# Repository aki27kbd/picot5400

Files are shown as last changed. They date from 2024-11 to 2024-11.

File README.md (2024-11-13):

# picot5400

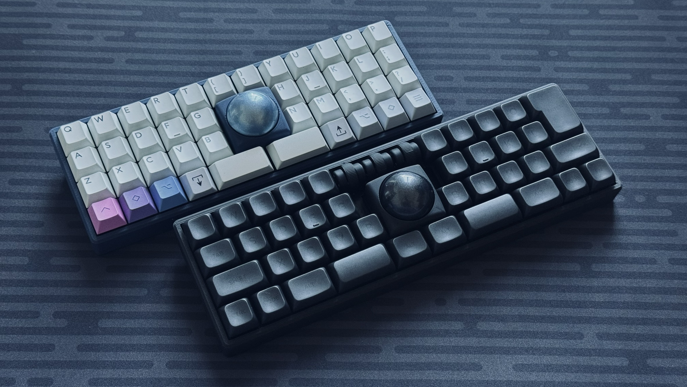
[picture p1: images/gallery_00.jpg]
picot5400_readme_00


## Introduction
picot5400 is a micro controller (RP2040) and trackball sensor (PMW3360) module for mechanical keyboard. Module size is 2u x 2u (38mm x 38mm) so that it can be easily implemented with mechanical keyboard design. The picot5400 allows designers to quickly and easily implement a trackball keyboard with only key matrix circuit and PCB.

## Features
- On-board MCU (RP2040) allows a full functional firmware with a trackball, vial and RGB matrix
- High-performance sensor (PMW3360) up to 12,000 cpi
- USB connection flexibility - an on-board Type-C connector as well as a JST connector for Unified Daughterboards
- Sufficient GPIO pins available - 21 pins via 24-pin flexible flat cable and 7 pins via through holes.
- Bearing roller support with a smooth ball handling and easy assembly

## How to Use
Please visit the docs for [consumers](doc/buildguide.md) and [designers](doc/designguide.md).

## Previews

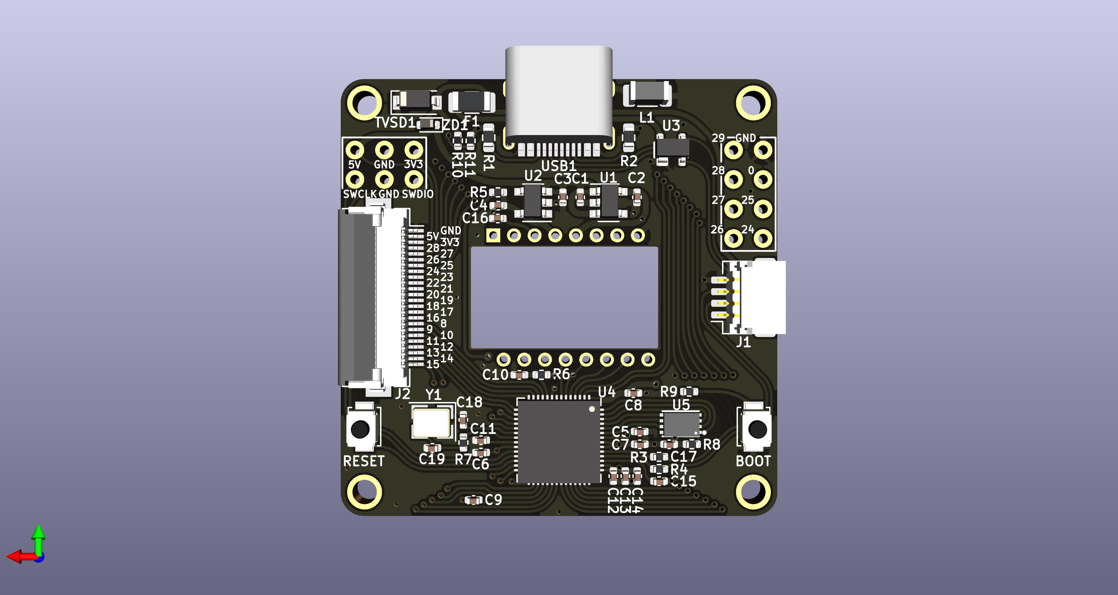
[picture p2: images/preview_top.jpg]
picot5400_preview_top


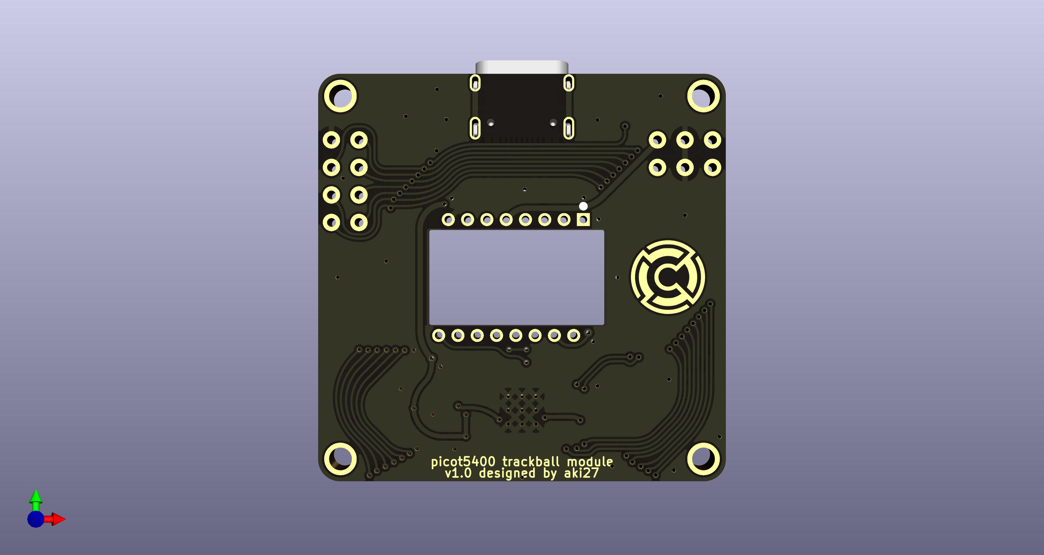
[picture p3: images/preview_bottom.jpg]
picot5400_preview_bottom


## Reference Keyboards

[picot_O44](https://github.com/aki27kbd/picot_o44)  
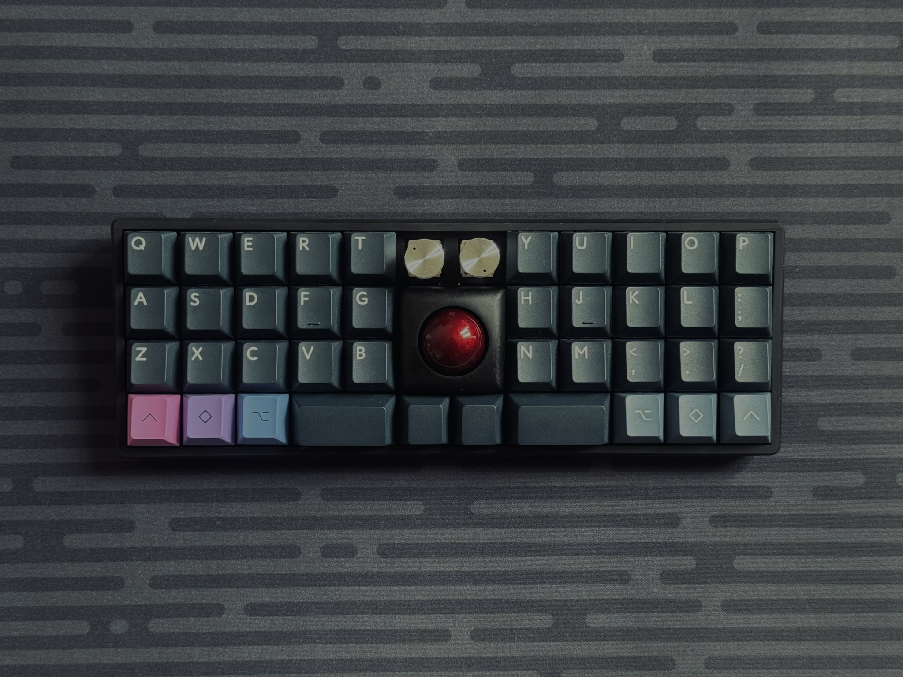
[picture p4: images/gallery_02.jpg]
picot_O44


[picot_R40](https://github.com/aki27kbd/picot_r40)
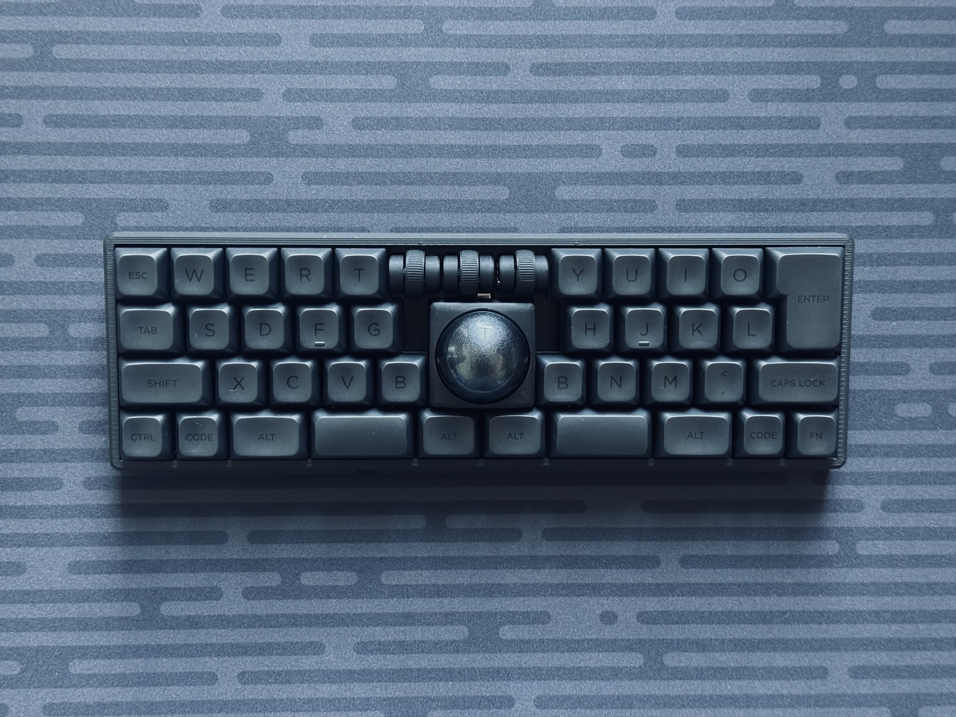
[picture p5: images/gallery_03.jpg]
picot_R40


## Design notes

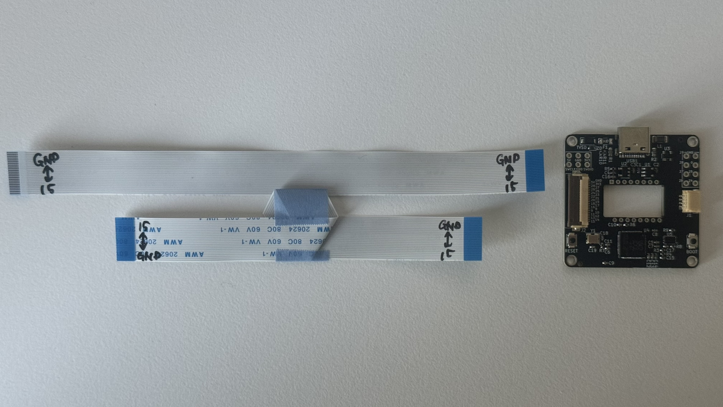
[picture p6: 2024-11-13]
images/design/FFC_02.jpg

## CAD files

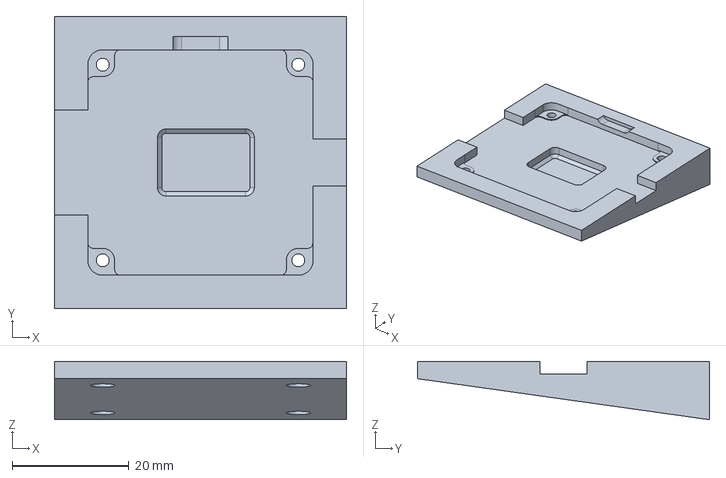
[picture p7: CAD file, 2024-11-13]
resources/picot5400_case_sample_8deg.step
50.0 x 50.0 x 10.0 mm

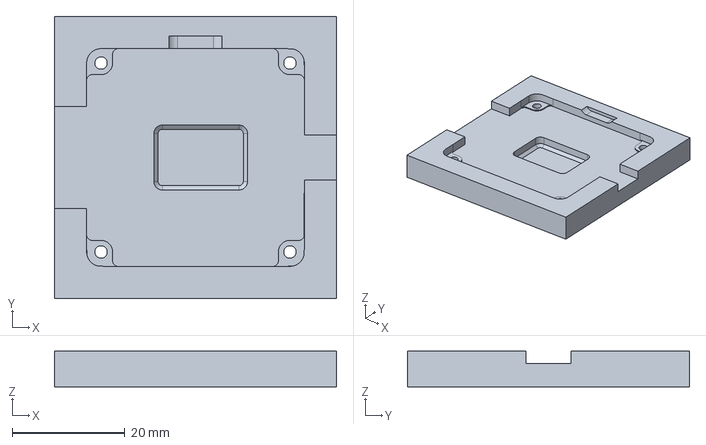
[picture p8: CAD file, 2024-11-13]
resources/picot5400_case_sample.step
50.0 x 50.0 x 6.30 mm

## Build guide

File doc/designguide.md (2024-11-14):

# Design Guide

picot5400を用いたキーボードのデザインガイドになります。picot5400を用いることで、トラックボール付キーボードの設計がしやすくなります。  
picot5400を採用したキーボードであるpicot_O44を例に挙げます。下図はpicot_O44の全体構成概略図になります。  
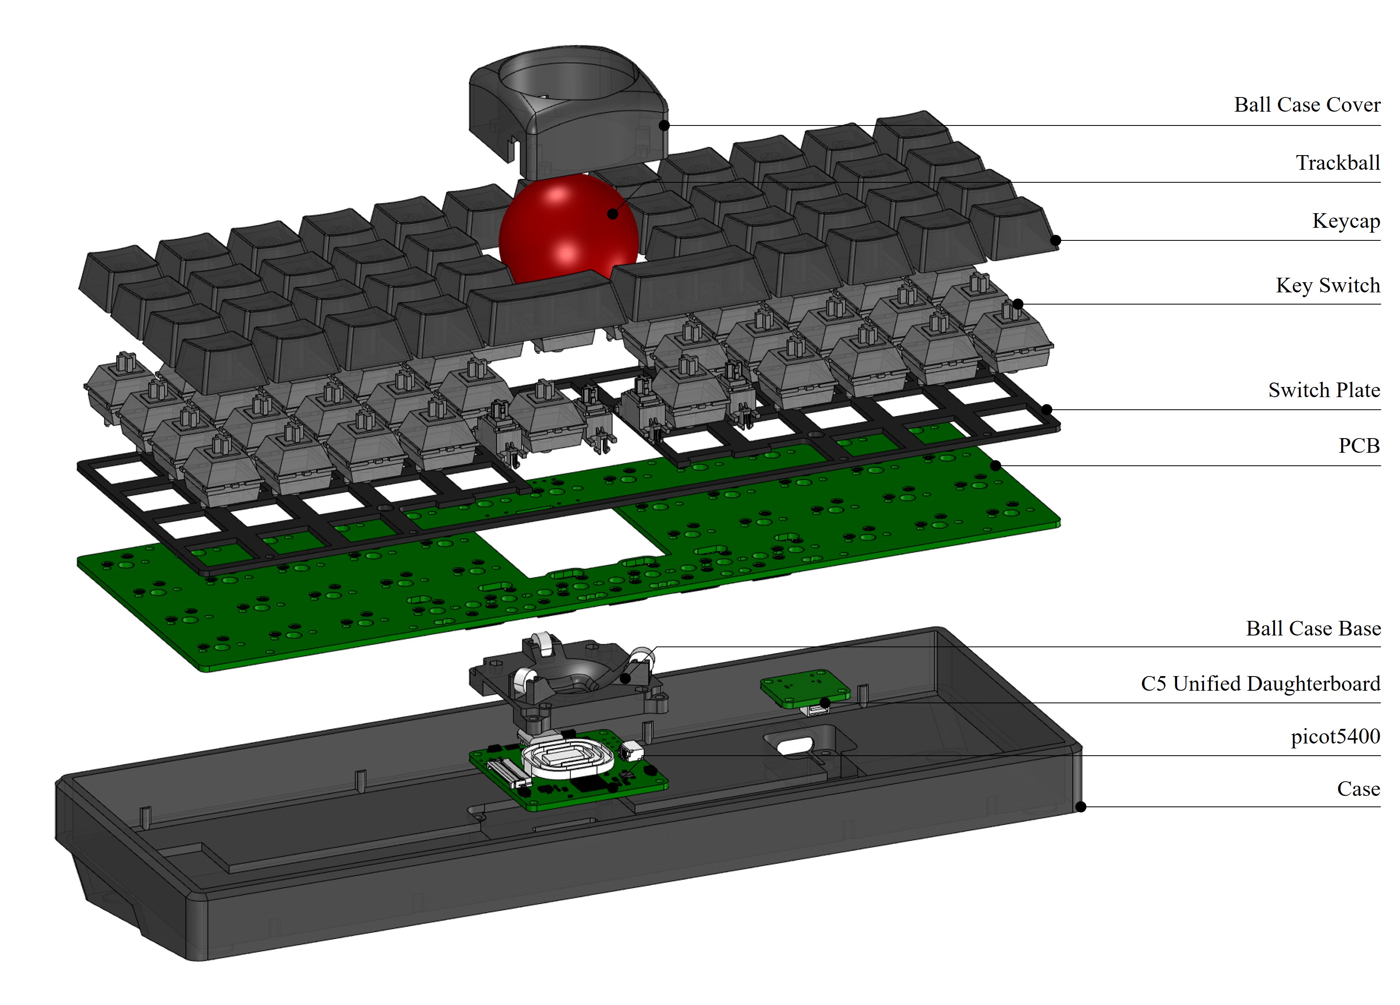
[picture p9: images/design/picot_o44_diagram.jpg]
picot_o44_diagram
  

picot_O44では、picot5400をケースに固定し、同じくケースに固定したUnified DaughterboardとJSTケーブルで接続します。  
キーマトリクス基板（PCB）はpicot5400とフレキシブルフラットケーブルで接続されます。  
このデザインガイドでは、キーマトリクス基板とケースの設計について留意すべき点を中心にまとめています。一般的なキーボード用PCBやケースデザインの基礎については他資料を参照してください。

## PCB Design

キーボードを設計する際は、picot5400とフレキシブルフラットケーブルを介して接続するキーマトリクス基板が必要になります。マイコン（RP2040）およびセンサー（PMW3360）は全てpicot5400側に搭載されているので、キーマトリクス基板はGPIOと電源線のみで構成することが可能です。

### Circuit Design
回路図には、左側のFFCコネクタと右側のキーマトリクスが必要です。  
[picot_o44_schematics.pdf](https://github.com/aki27kbd/picot_o44/blob/main/doc/picot_o44_schematics.pdf)  
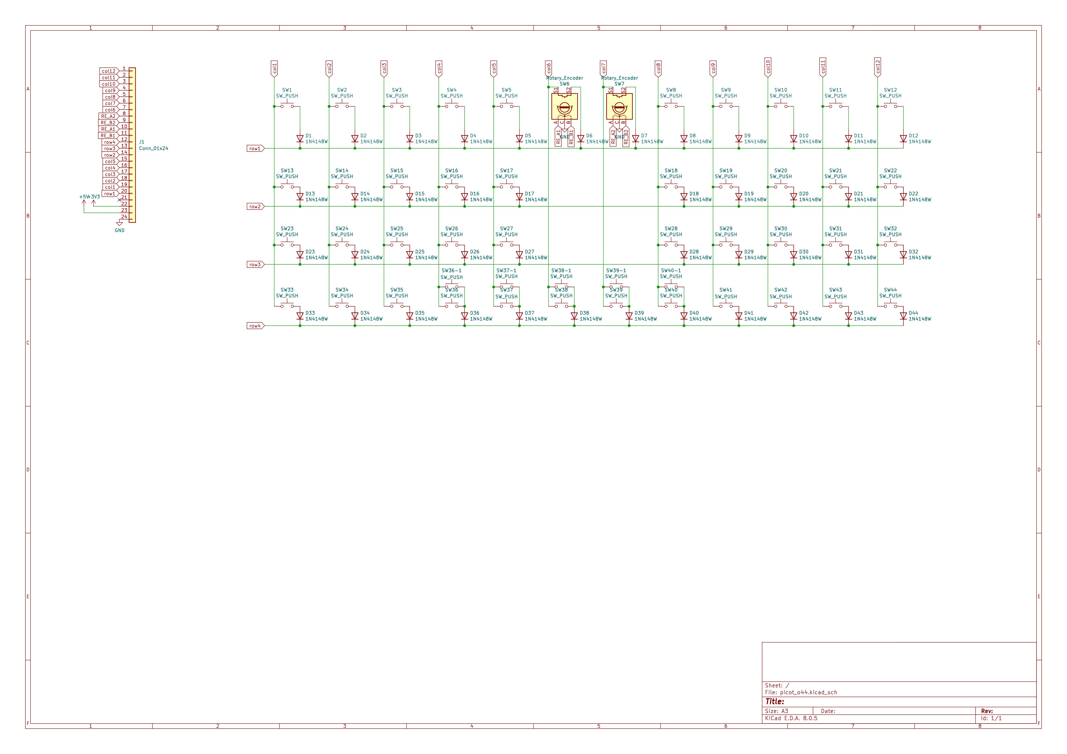
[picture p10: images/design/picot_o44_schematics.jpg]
picot_o44_schematics


FFCコネクタは、使用するケーブルの種類（ストレート・反転）に応じて、ピンの配置を反転させてください。picot_O44では、ストレートタイプのケーブルを用いて、基板底面にコネクタを配置しています。下図のように、***ストレートタイプのケーブルを用いる場合はpicot5400とキーマトリクス基板でコネクタのピンアサインが反転することに注意してください。***  
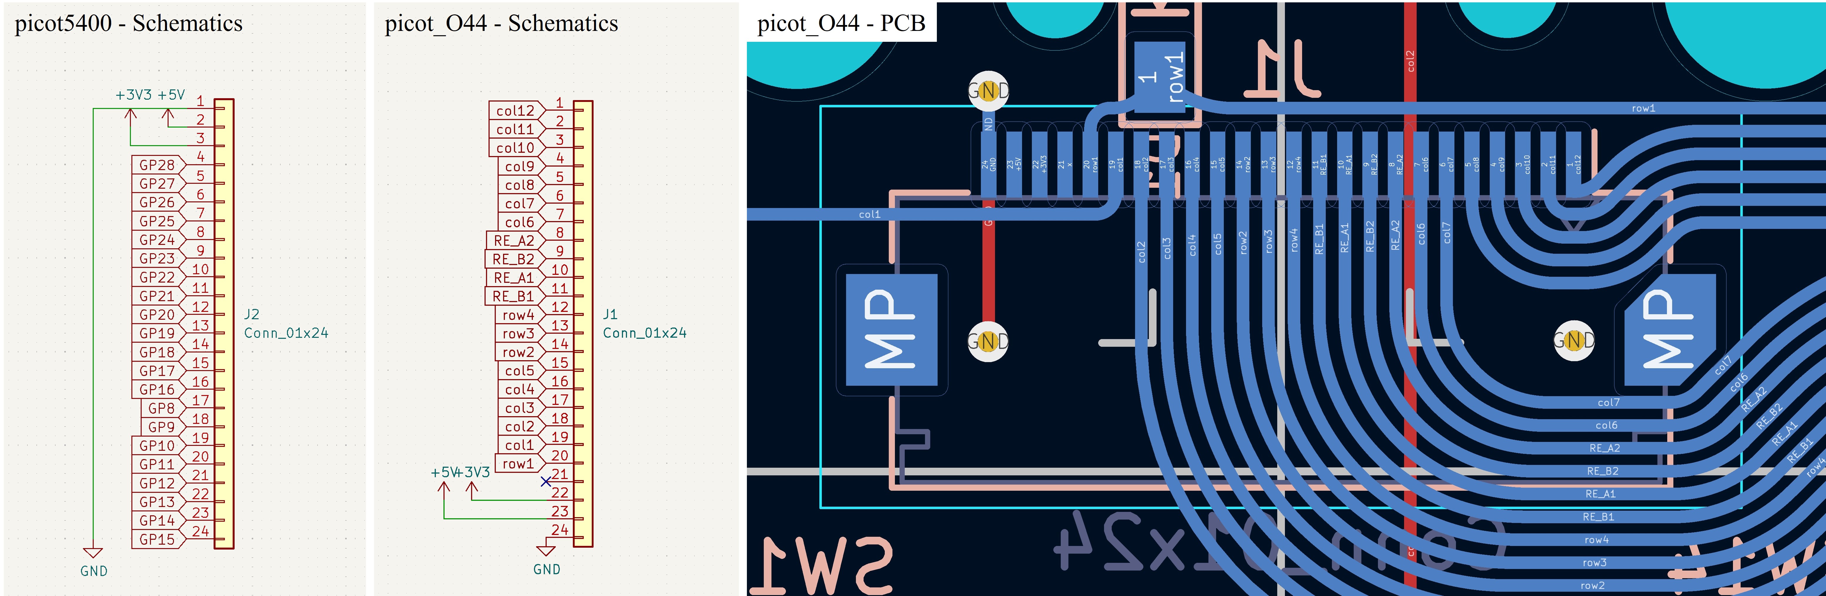
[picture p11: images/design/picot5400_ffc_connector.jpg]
picot5400_ffc_connector


コネクタのピンアサインを誤って逆にしてしまった場合でも、ケーブルを折り曲げることで対応可能です。  
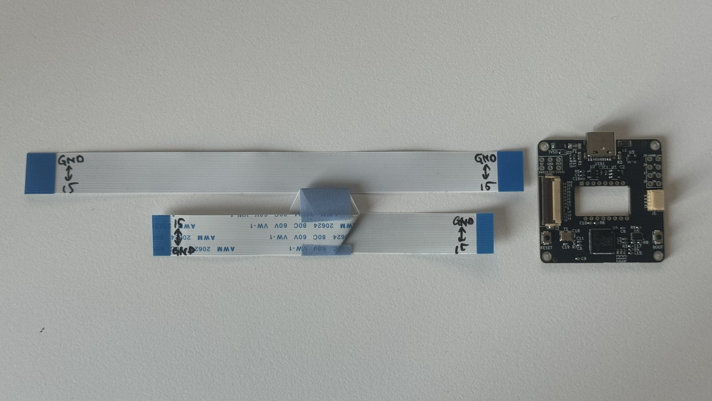
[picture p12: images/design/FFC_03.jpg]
FFC_reversed


キーマトリクス側は、通常のキーボードと同様に設計してください。FFCケーブルで接続した場合、最大21本のGPIOを使用することが可能なので、キー数の多いキーボードやロータリーエンコーダにも十分に対応可能です。  
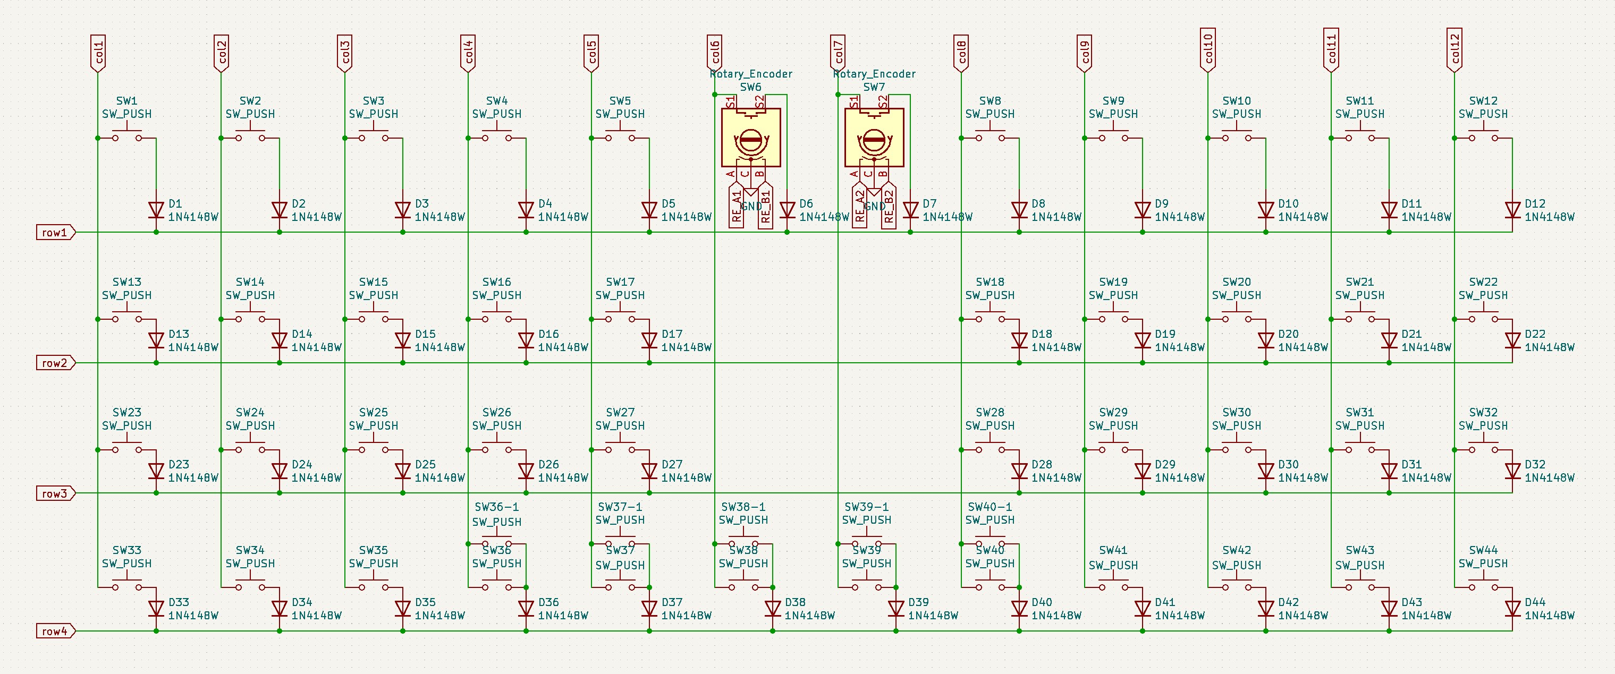
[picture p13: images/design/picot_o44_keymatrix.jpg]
Keymatrix


### PCB Design
キーマトリクス基板側のFFCコネクタは、KiCADのデフォルトライブラリに入っている「Hirose_FH12-24S-0.5SH_1x24-1MP_P0」を使用します。
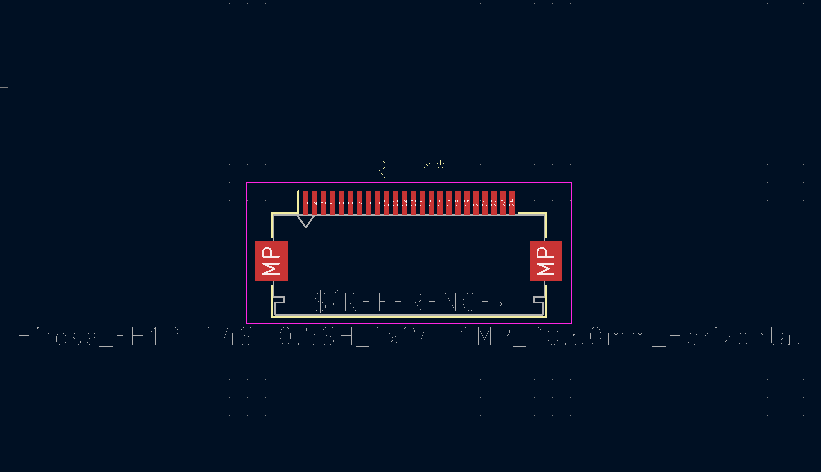
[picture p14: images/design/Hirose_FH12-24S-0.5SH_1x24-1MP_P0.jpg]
Hirose_FH12-24S-0.5SH_1x24-1MP_P0


コネクタはキーの間に設置することが可能です。スイッチソケットを扱う場合もキー間に設置可能です。  
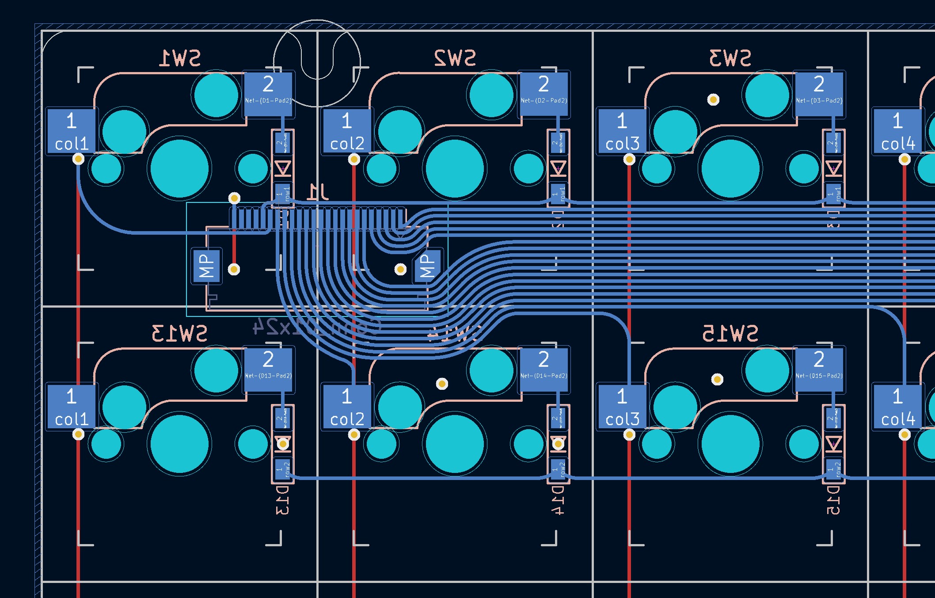
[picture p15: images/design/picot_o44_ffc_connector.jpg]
picot_o44_ffc_connector


picot_O44のようにキーボードの中央にトラックボールを設ける場合、キーマトリクス基板の該当箇所に必要な開口を設けてください。  
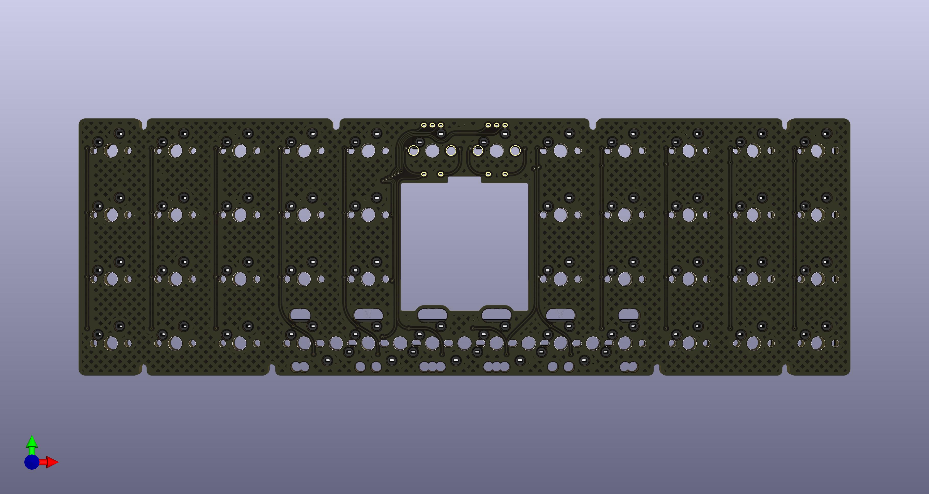
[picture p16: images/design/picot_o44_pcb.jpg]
PCB


picot_O44のPCBには、picot5400のUSB Type-Cとの干渉を避けるための切り欠きが設けられています。設計上はPCBとUSB Type-Cは干渉しませんが、PCBが想定以上に撓んだ場合を想定して該当箇所を切り欠いています。  
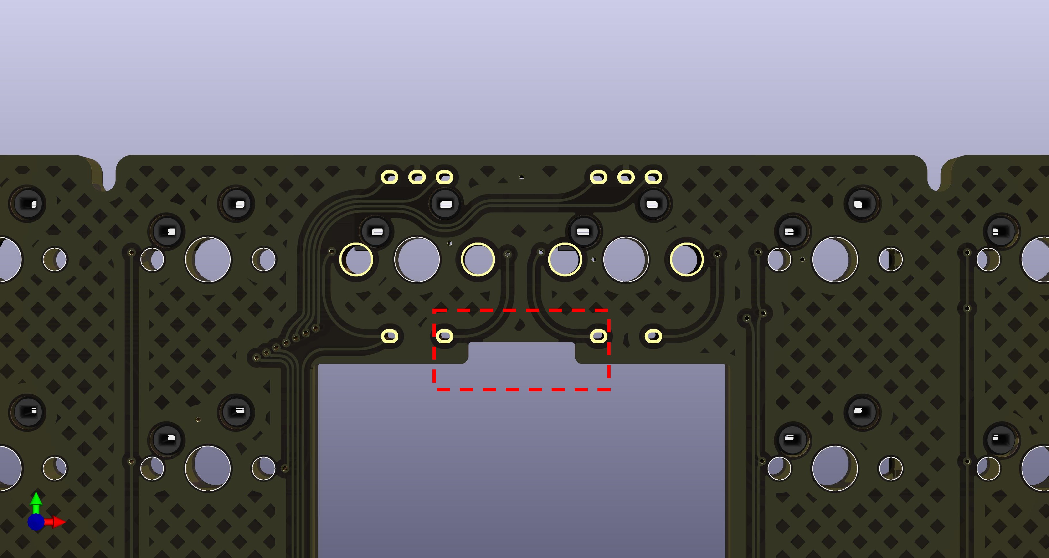
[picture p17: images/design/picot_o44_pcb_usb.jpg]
PCB_USB


また、picot_O44のようにスタビライザーを固定するためにPCBが開口側にはみ出す場合もあります。その場合はボールケース（ベース）の切り欠きがある側をスタビライザー側になるように設計してください。
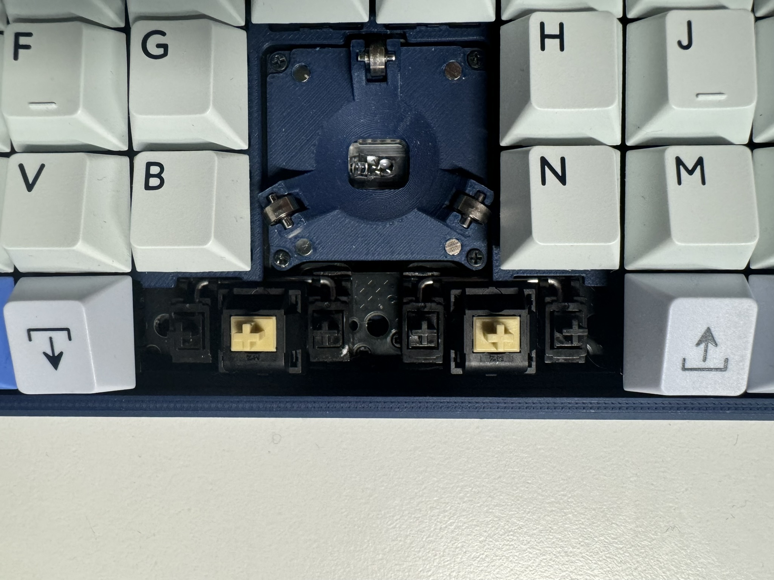
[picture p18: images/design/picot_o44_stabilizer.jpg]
PCB_stabilizer


## Case Design
picot5400は、キーボードのケースやボトムプレートなど、キーマトリクス基板から独立したものに固定することを推奨しています。これはキーの押下に伴う基板の揺れがセンサーとボールに伝わりにくくするためです。

picot_O44では、picot5400を直接キーボードのケースに固定し、キーマトリクス基板はケースを介して間接的に接触する設計としています。
断面図での各パーツの構成は下図の通りです。  
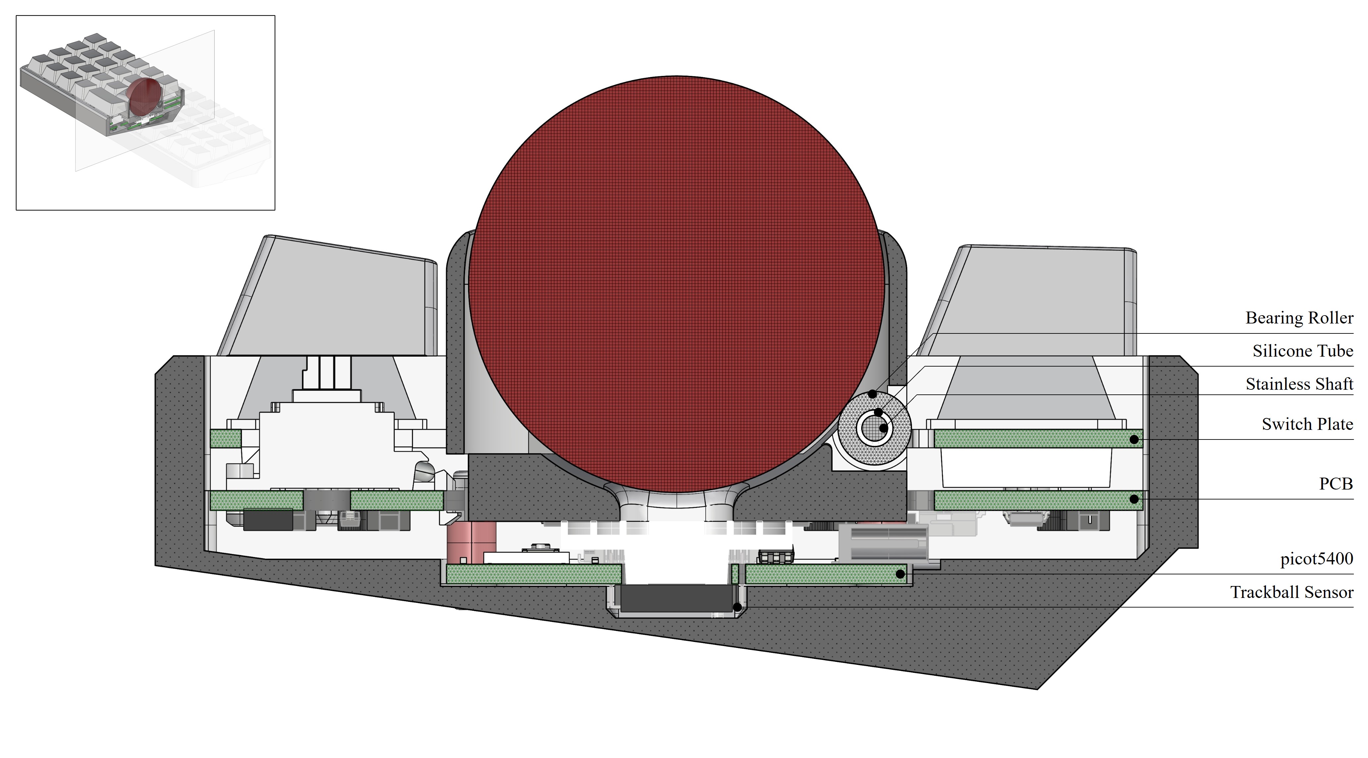
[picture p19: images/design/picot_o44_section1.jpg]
picot_o44_section1
  

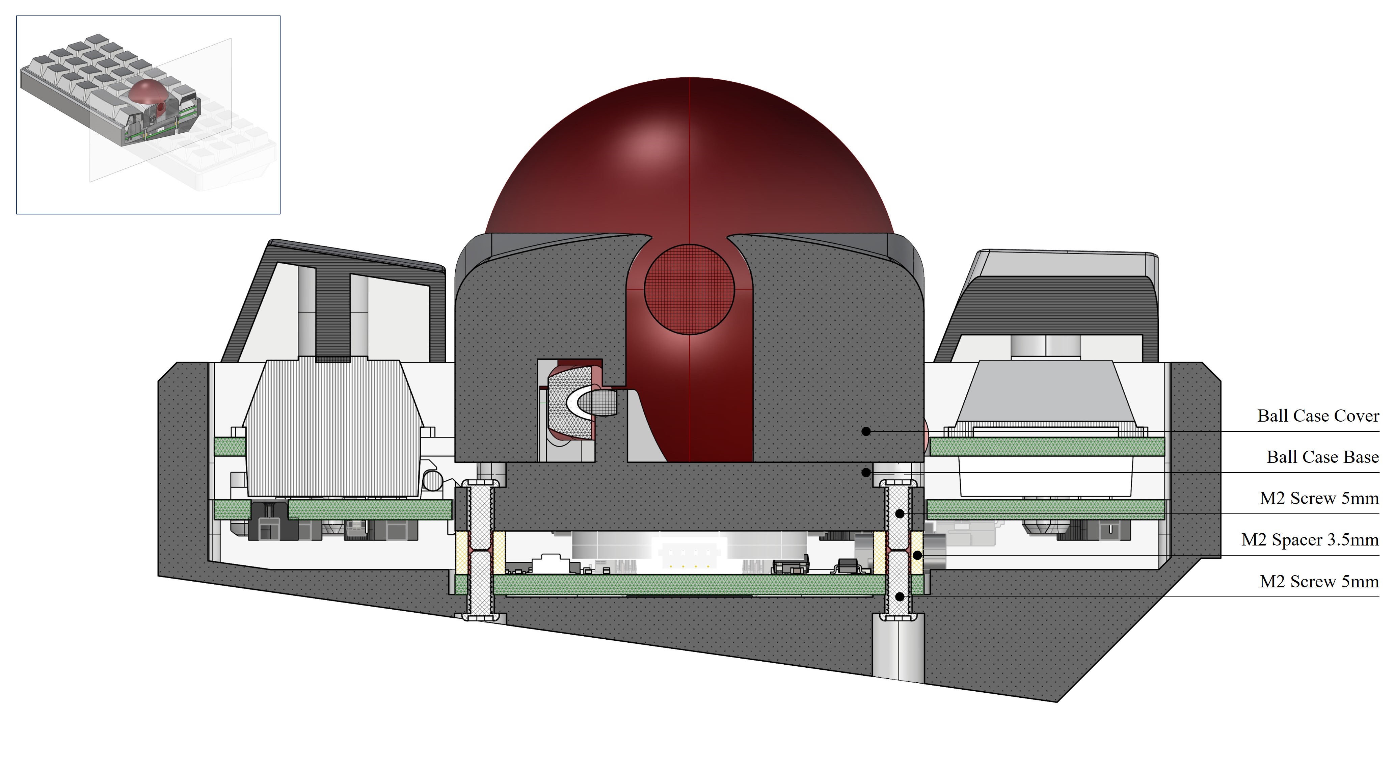
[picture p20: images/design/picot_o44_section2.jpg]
picot_o44_section2
  

キーボードのケースやボトムプレートに固定する際のねじ穴寸法は、下の寸法図を参考にしてください。  
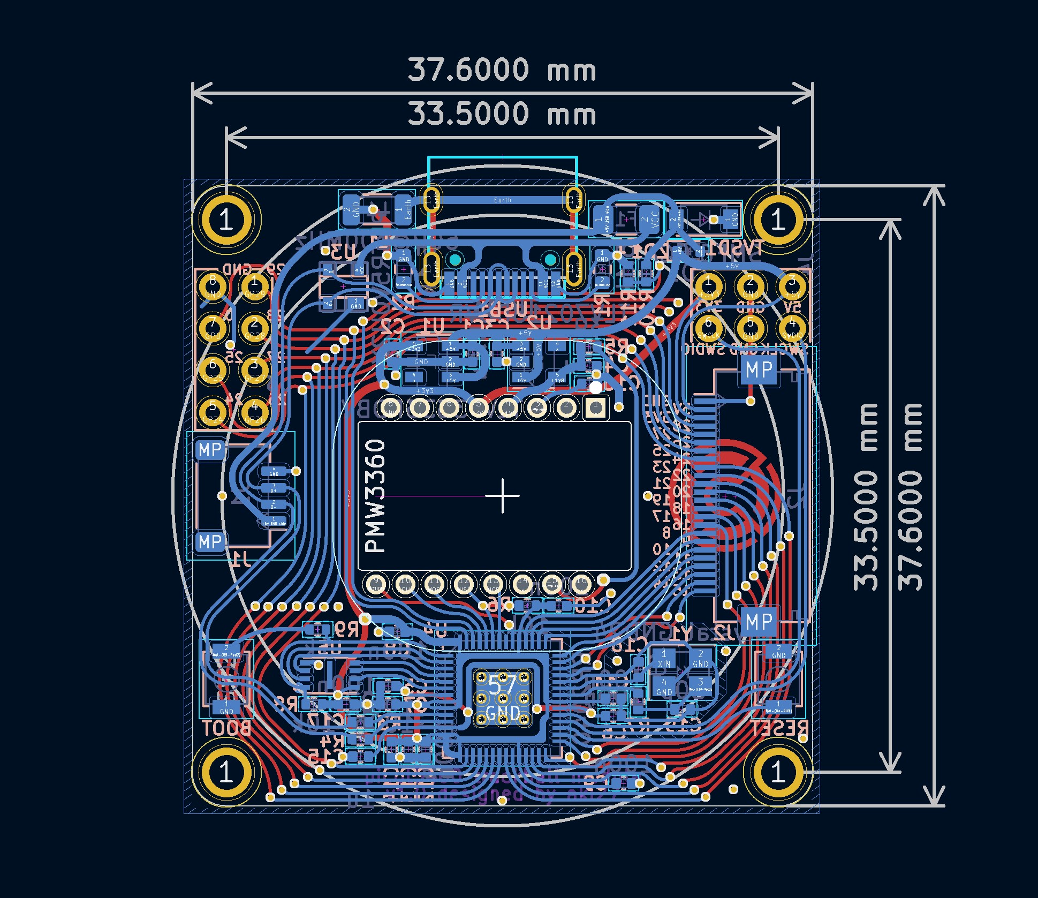
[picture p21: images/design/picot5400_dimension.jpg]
picot5400_dimension
  

また、3DプリンタやCNCで製造する立体的なケースを設計する際は、下記資料内の[picot5400_case_sample](/resources/picot5400_case_sample.step)を参照してください。  
下記ポイントに注意して設計を進めてください。
- picot5400の下部にセンサーが出っ張るため干渉を避ける必要があります
- USB Type-Cコネクタが基板外径線からはみ出しているので、基板をケースに埋め込む際はコネクタと干渉しないよう切り欠きを設ける必要があります
- FFCケーブル、JSTケーブルは基板上面のコネクタに接続するので、基板をケースに埋め込む際はケーブルルート用の切り欠きを設ける必要があります

USBコネクタは、picot5400に搭載されているものを用いない場合はJSTケーブルでUnified Daughterboardと接続することになります。  
Unified Daughterboardに関する設計は[公式ドキュメント](https://unified-daughterboard.github.io/#/?id=unified-daughterboard)を参照してください。

## Resources
[picot5400_schematics](/resources/picot5400_schematics.pdf)  
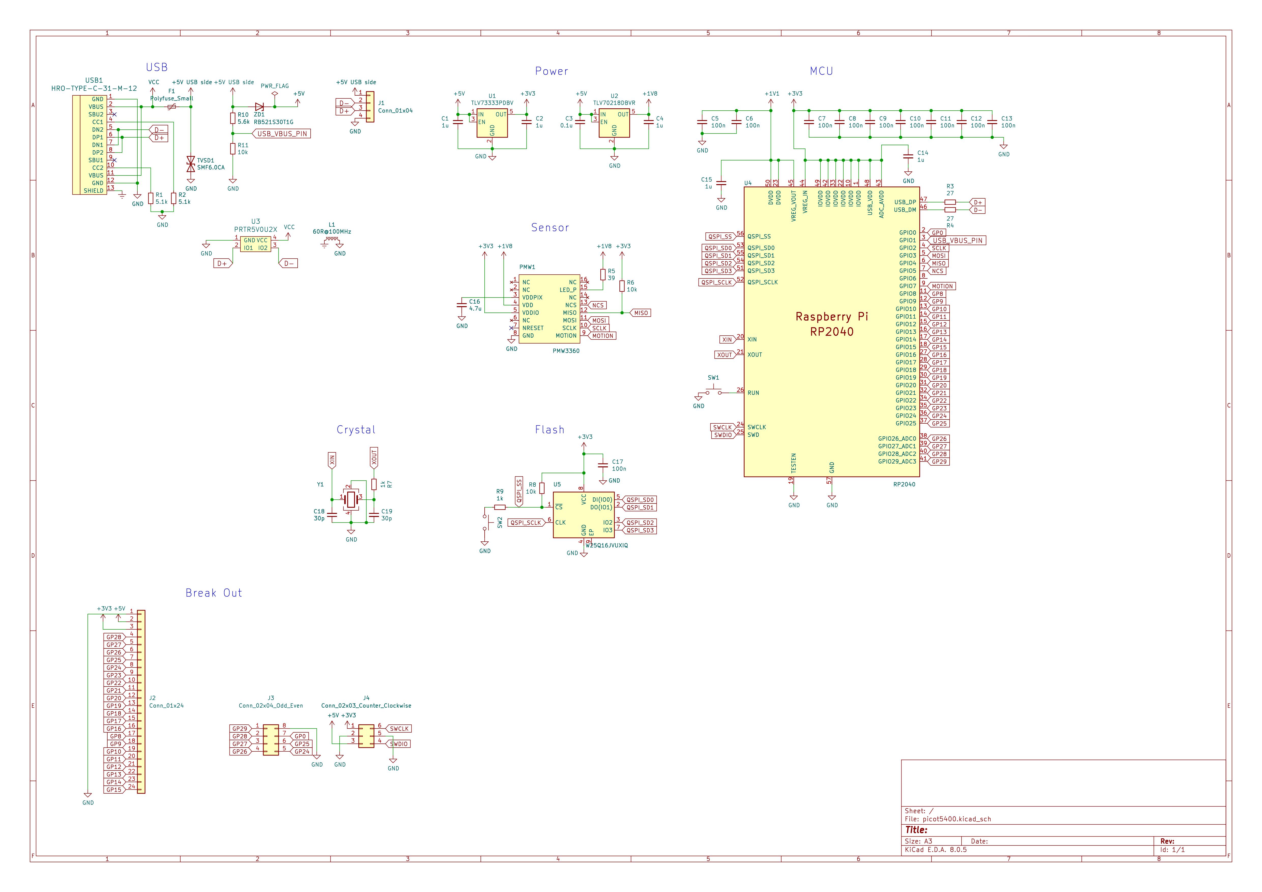
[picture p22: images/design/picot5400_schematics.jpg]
picot5400_scematics
  

[picot5400_step](/resources/picot5400.step)  
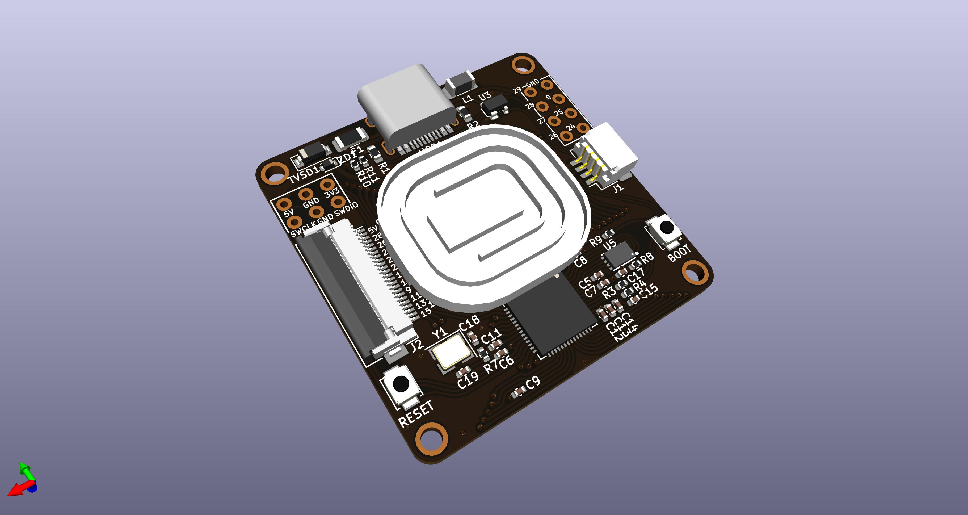
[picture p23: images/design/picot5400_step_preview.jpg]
picot5400_step_preview
  

[picot5400_case_sample](/resources/picot5400_case_sample.step)
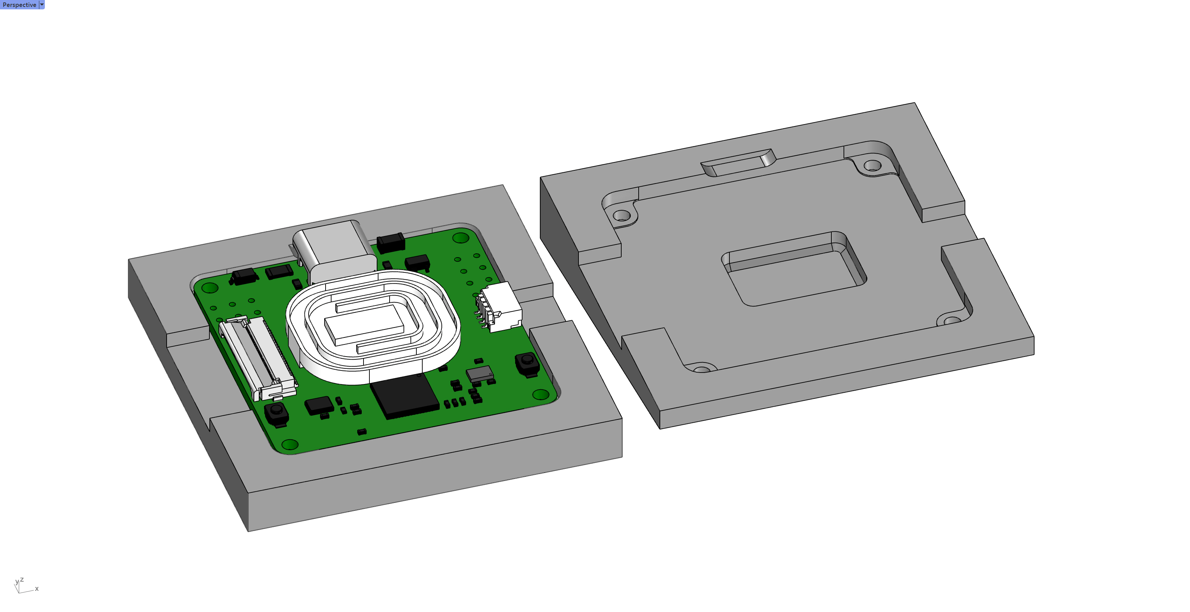
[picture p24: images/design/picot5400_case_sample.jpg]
picot5400_case_sample


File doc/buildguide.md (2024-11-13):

# Build Guide

picot5400_gallery_00

For English version, please visit [buildguide_en.md](buildguide_en.md)

picot5400のビルドガイドになります。  

picot5400は、マイコン（RP2040）とトラックボールセンサー（PMW3360）を1枚のボードに搭載したモジュールです。  
picot5400を用いたキーボードを組み立てる際は、このページを参照しながらモジュールの組み立てを行ってください。その他の組み立て工程は各キーボードのビルドガイドを参照してください。

## BOM

|名前|数|備考|
|---|---|---|
|picot5400 PCB|1||
|マウスセンサー（PMW3360）|1||
|M2スペーサー 3.5mm|4||
|M2ねじ 5mm|8||
|ベアリングローラー|3||
|ステンレス丸棒（直径:2mm, 長さ:6mm）|3||
|シリコンチューブ（内径:2mm, 外径:3mm）|1||
|マグネット（直径:2mm, 高さ:2mm）|8||
|3Dプリントボールケース（ベース・カバー）|1||

## 組み立て
### picot5400

  まずpicot5400をUSB接続し、PCに認識されるかを確認してください。  
  ***この工程は必ずはんだ付けを行う前に行ってください。はんだ付けを行った後に動作確認ができない場合は初期不具合には含まれませんのであらかじめご了承ください。***  

  USB機器として認識されることが確認できたら、マウスセンサーを取り付けます。  
  センサー基板にマウスセンサー（PMW3360）を基板裏面から写真の向きに設置し、表面からはんだ付けを行います。シルクの●印と基板の●印の位置が合うように注意してください。    
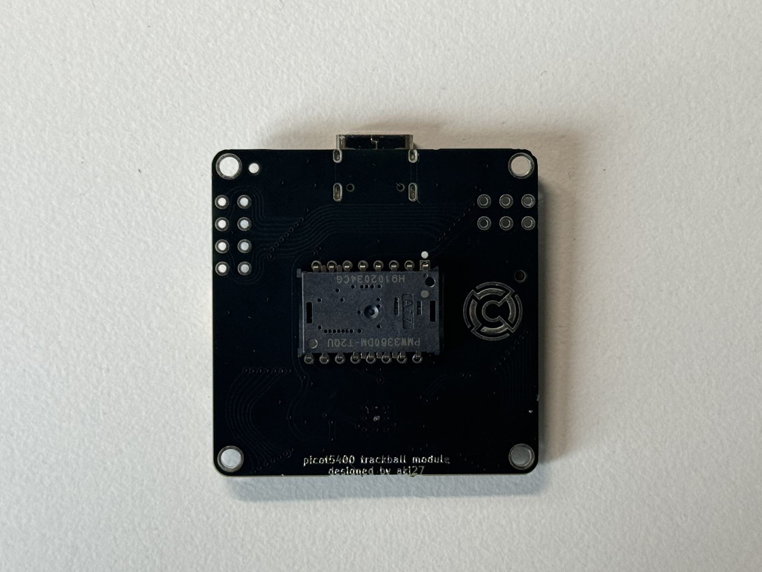
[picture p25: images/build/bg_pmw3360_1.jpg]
picot5400_bg_pmw3360_1
  

  センサーの脚がしっかり奥まで入った状態で、浮かないようにマスキング テープなどで固定します。  
  表面から16本の脚をはんだ付けします。***はんだ付けは必ずUSBケーブルを外した状態で行ってください。***  
  センサーに貼られているテープを剥がし、表面からレンズを付けます。    
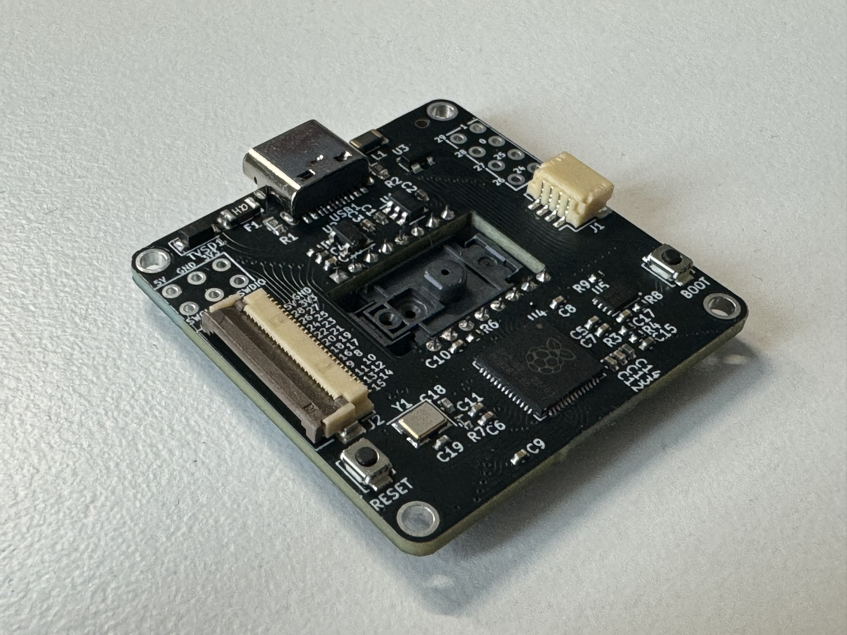
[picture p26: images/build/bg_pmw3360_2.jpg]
picot5400_bg_pmw3360_2
  

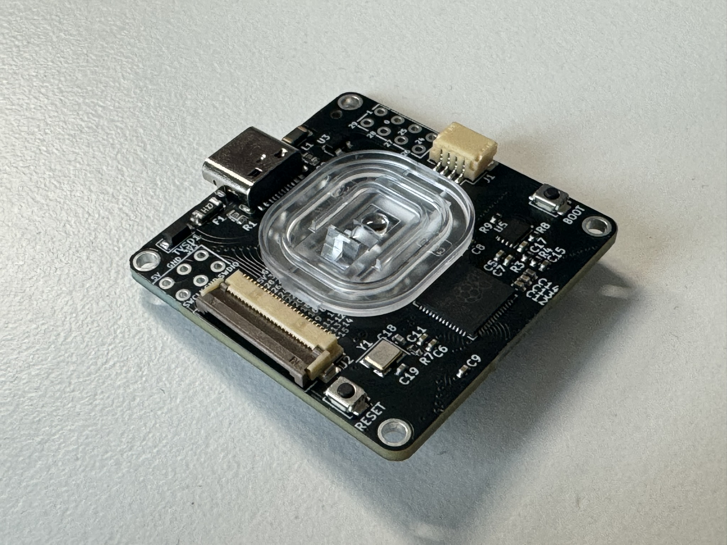
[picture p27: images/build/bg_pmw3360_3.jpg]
picot5400_bg_pmw3360_3
  

  レンズを取り付けたら、再度USBに接続し、レンズ上部に手をかざしてカーソルが動くことを確認してください。

  レンズが浮かないようにしっかりと差し込んだら、裏面からレンズの突起にはんだごてを少しあて、レンズを溶かして固定します。
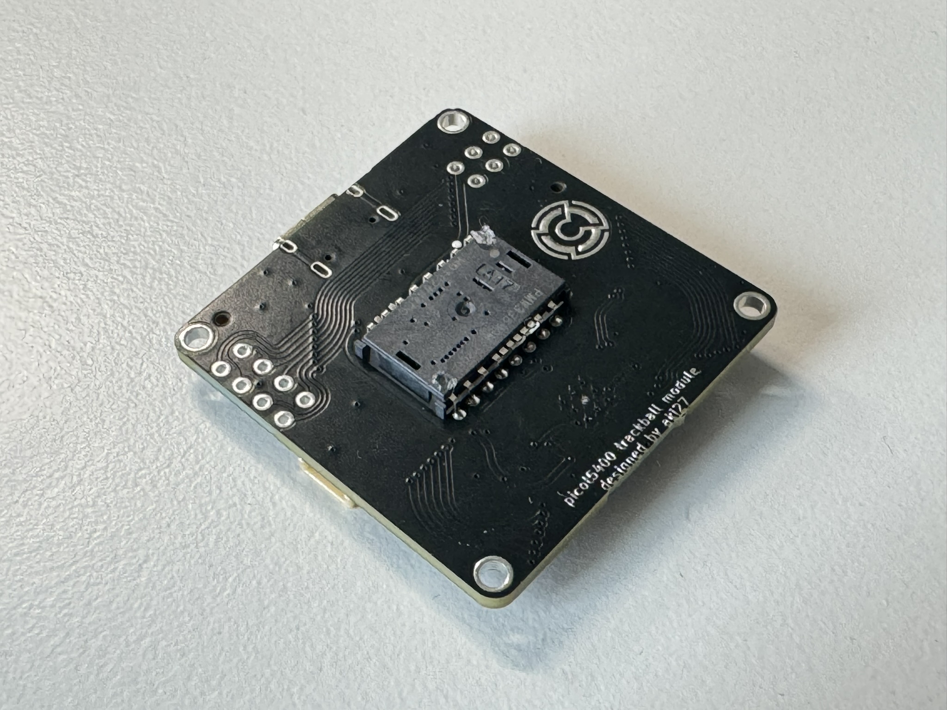
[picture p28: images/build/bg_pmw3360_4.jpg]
picot5400_bg_pmw3360_4
    

### ボールケース

　細い方のシリコンチューブを、3mm程度の長さで3本切ります。ハサミなどで簡単に切れますが、できるだけ切断面が真っすぐになるように注意してください。  
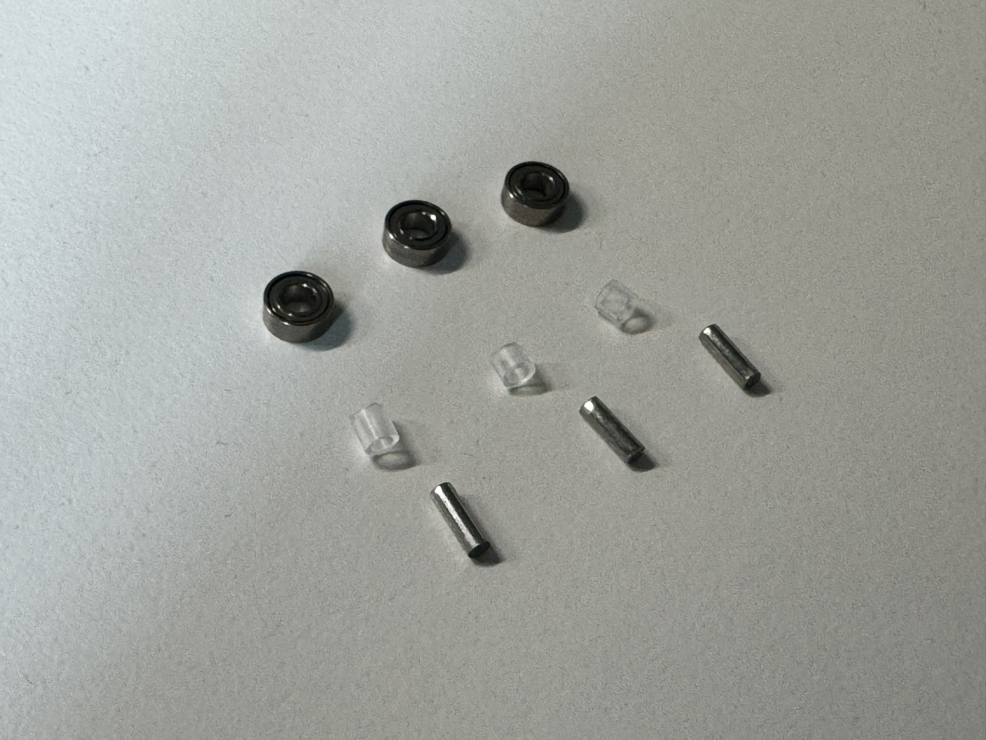
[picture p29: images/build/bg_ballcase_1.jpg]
picot5400_bg_ballcase_1
    

  ステンレス丸棒を切り出したシリコンチューブの中に通します。
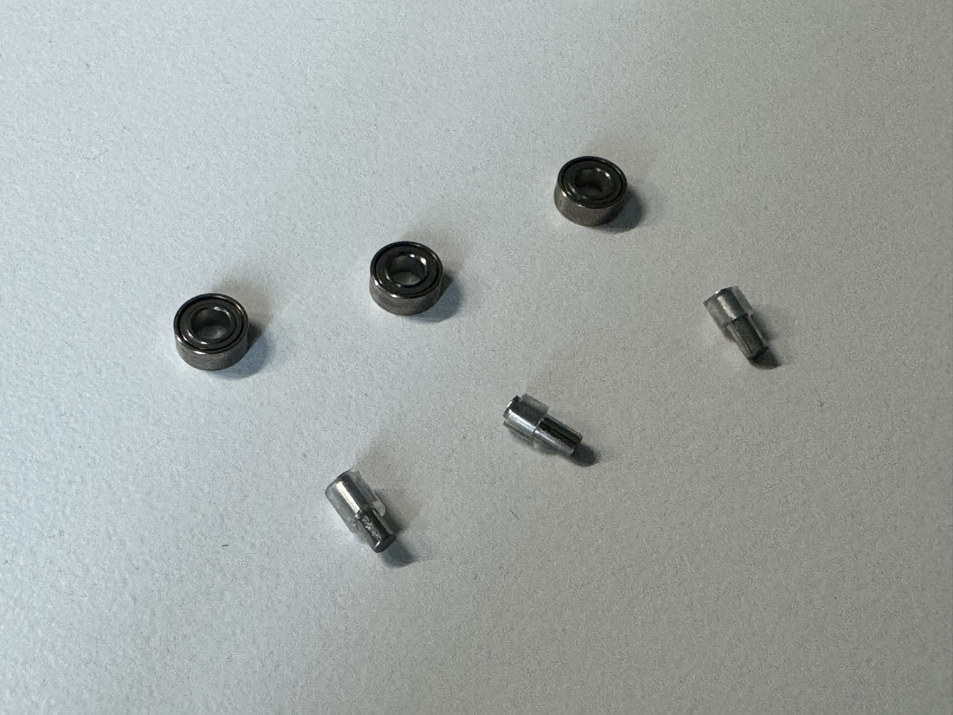
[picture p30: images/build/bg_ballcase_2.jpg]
picot5400_bg_ballcase_2
    

  ベアリングローラーをシリコンチューブの外側に通し、チューブとベアリングがステンレス丸棒の中央に来るように調整します。
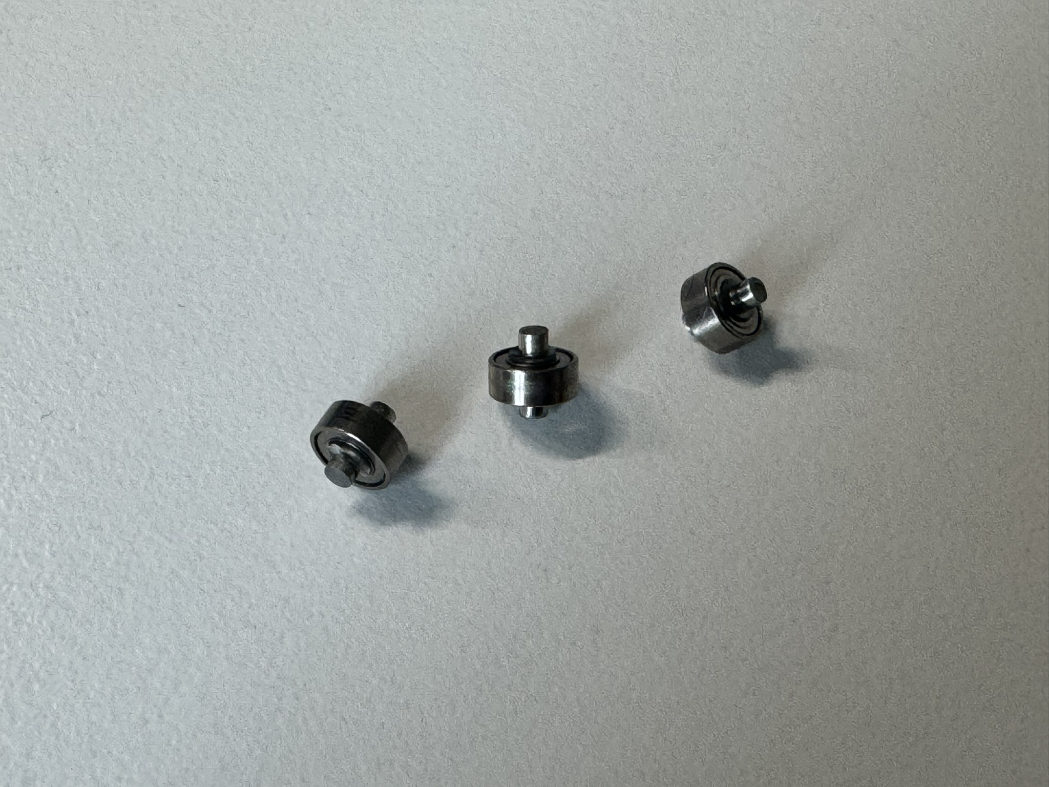
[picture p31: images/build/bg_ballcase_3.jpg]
picot5400_bg_ballcase_3
    

  ボールケース（ベース）の3本の台座に、ベアリングローラーをはめたステンレス丸棒を装着します。真上からカチッと音がするまで押し込んでください。ステンレス丸棒が台座から飛び出していなければOKです。
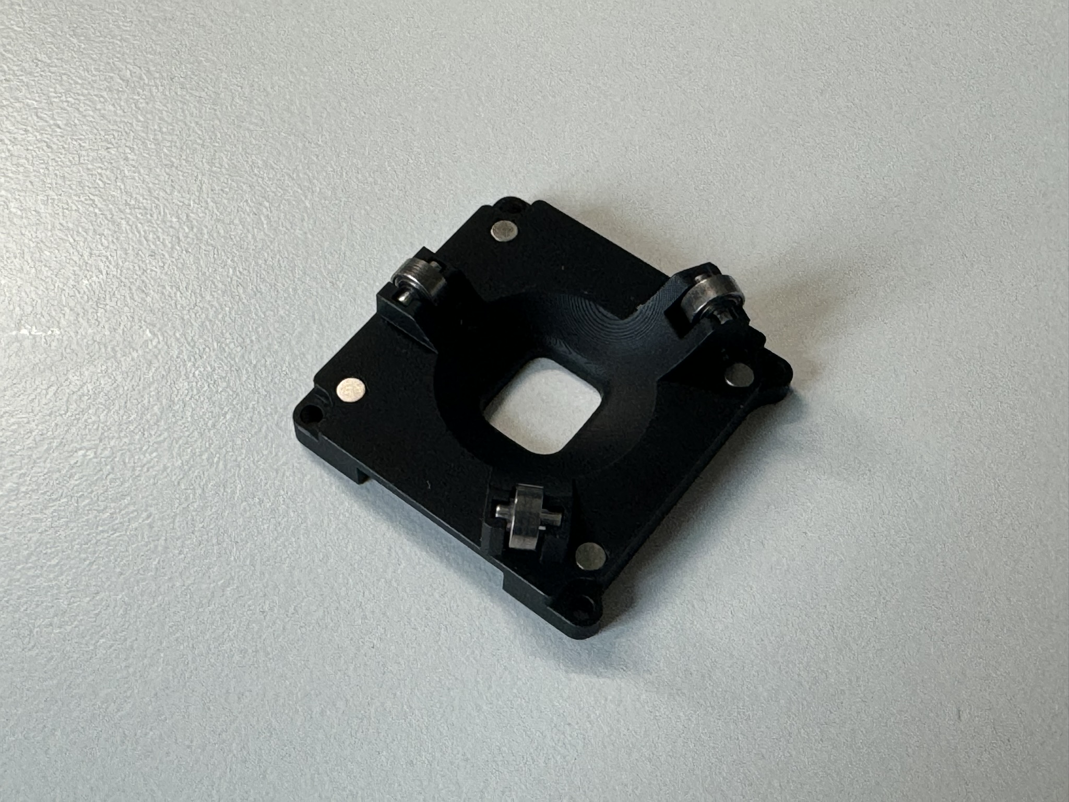
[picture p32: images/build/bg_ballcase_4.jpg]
picot5400_bg_ballcase_4
    

  ボールケース（ベース）の四隅下側にスペーサーを固定します。  
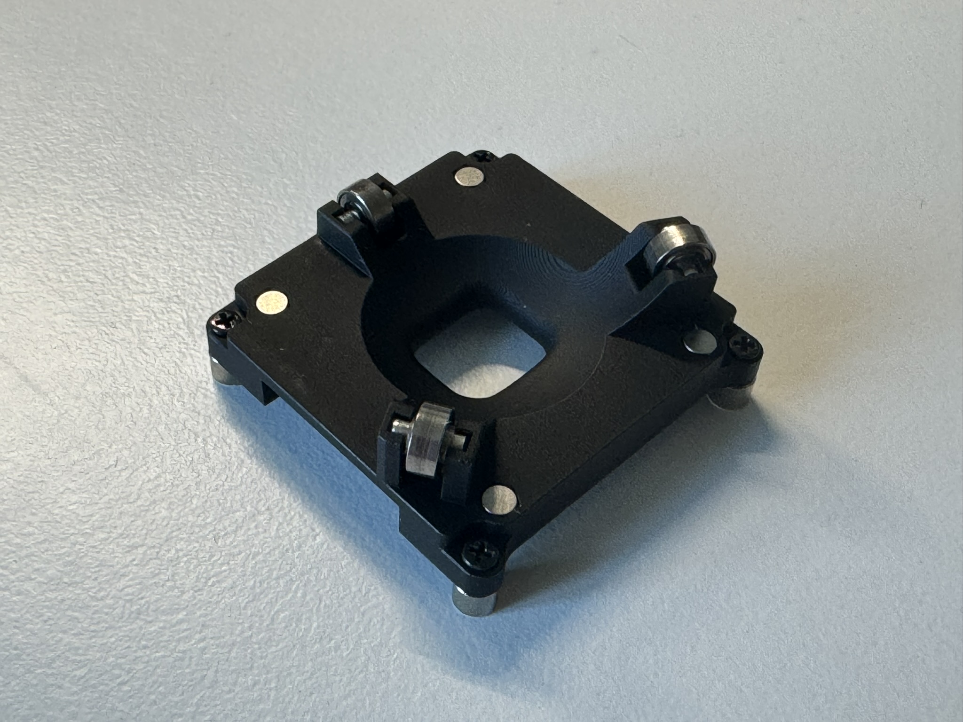
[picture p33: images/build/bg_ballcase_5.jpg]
picot5400_bg_ballcase_5
    

  picot5400の上にボールケースを重ねます。各キーボードのケースやボトムプレートに重ね、下からねじで固定します。詳細は各キーボードのビルドガイドを参照してください。  
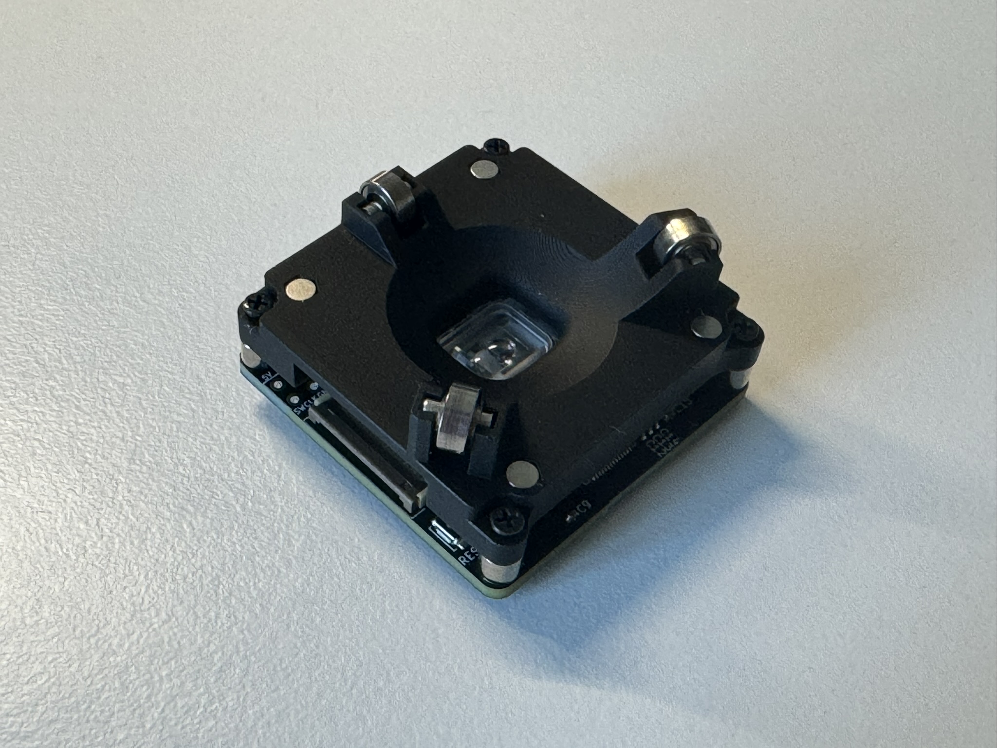
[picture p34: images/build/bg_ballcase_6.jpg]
picot5400_bg_ballcase_6
    

## ファームウェア

  ご自分でファームを書き込む場合、下記手順の通り実行してください。

  - picot5400のBOOTボタンを押しながらRESETボタンを押し、ブートローダーモードに入ります。
  - その状態でRPI-RP2というドライブに[.uf2](https://github.com/aki27kbd/picot5400/blob/main/firmware/aki27_picot5400_vial.uf2)ファイルをドラッグ&ドロップすることでファームが書き込まれます。　　

  キーマップは[vial](https://vial.rocks/)から更新可能です。  
  トラックボールの動作は後述のセンサー基板を組み立ててから行ってください。  
  vial

  デフォルトのファームウェアでは自動マウスレイヤー機能がオンになっています。この機能では、トラックボールを動かすと自動的にマウスレイヤー（レイヤー4）に移動することが可能です。カスタムキーコード（`AM_TOG`）を押すことで自動マウスレイヤー機能のオンオフを切り替えられます。

  ソースコードは[こちら](https://github.com/aki27kbd/vial-qmk/tree/vial/keyboards/aki27/picot_o44)を参照ください。      

## カスタムキーコード

  トラックボールの操作に関していくつかカスタムキーコードを設定することが可能です。（SCRL_MOはレイヤー4でのみ有効）

  Keycode   |Description
  ---------|-----------
  `CPI_SW`  |トラックボールのCPIを変更します。デフォルトのファームウェアでは、押すたびに200→400→800→1600→3200→200…という順番でCPIが変わります。
  `SCRL_SW` |スクロールモードにおけるセンサーの感度を変更します。数値が大きいほどスクロール量が小さくなります。
  `ROT_R15` |マウスセンサーのＹ軸を時計回りに15度回転させます。
  `ROT_L15` |マウスセンサーのＹ軸を反時計回りに15度回転させます。
  `SCRL_MO` |押されている間スクロールモードになります。（デフォルトファームではレイヤー4でのみ有効）
  `SCRL_TO` |押すたびにスクロールモードとマウスモードを切り替えます。（デフォルトファームでは無効）
  `SCRL_IN` |スクロール方向を反転させます。
  `AM_TOG` |自動マウスレイヤー切り替えのオンオフを切り替えます。

  vialでカスタムキーコードを設定する場合はUserタブ下のカスタムキーコードを用いて設定することが可能です。  
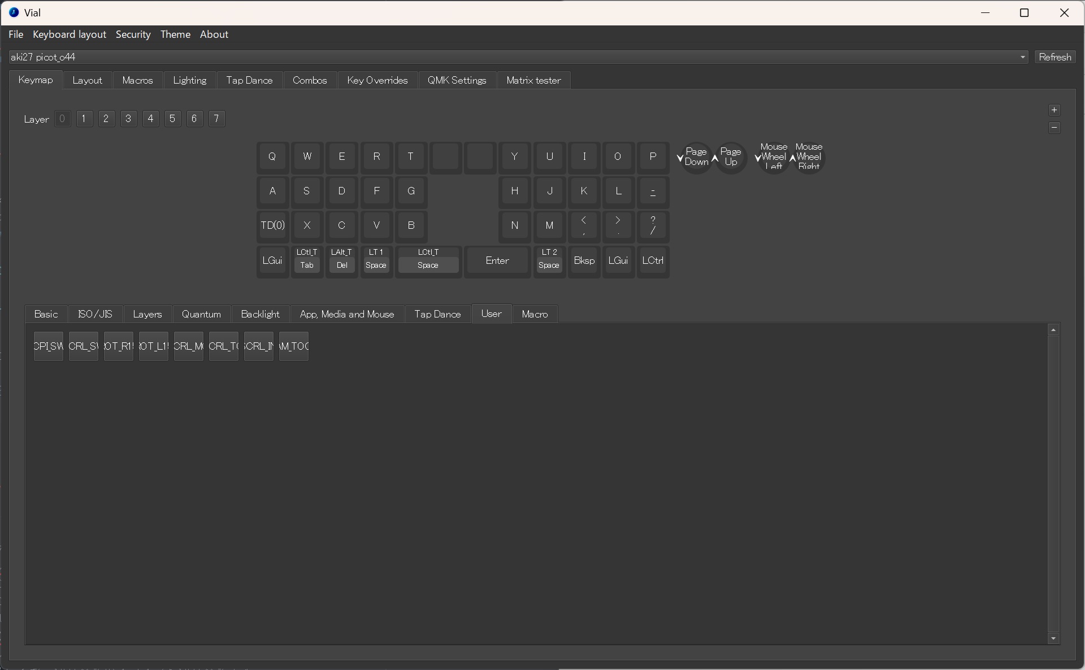
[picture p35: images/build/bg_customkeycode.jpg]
CustomKeycode_rev
  

## 終わりに
何かトラブルがあれば[Twitterアカウント](https://twitter.com/aki27kbd)までご連絡ください。

ハッシュタグは #picot5400 です。

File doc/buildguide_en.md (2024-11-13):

# Build Guide

picot5400_gallery_00

This is a build guide for picot5400.  

picot5400 is a micro controller (RP2040) and trackball sensor (PMW3360) module for mechanical keyboard.  
When building a keyboard with picot5400, please refer to this page for the assembly. Please refer to each keyboard's build guide for all other steps.

## BOM

|Parts|No.|Notes|
|---|---|---|
|picot5400 PCB|1||
|Sensor (PMW3360)|1||
|M2 Spacer 3.5mm|4||
|M2 Screw 5mm|8||
|Bearing Roller|3||
|Stainless Pin (R=2mm, L=6mm)|3||
|Silicone Tube (ID:2mm, OD:3mm)|1||
|Magnet (R=2mm, D=2mm)|8||
|3D Printed Ball Case (Base + Cover)|1||

## Assembly
### picot5400

  First, connect picot5400 to the USB and check if it is correctly recognized by the PC  
  ***This process must be done before soldering. Please note that if the operation cannot be confirmed after soldering, it is not included in the initial defects.***  

  After confirming that the device is recognized as a USB device, install the mouse sensor. Install the mouse sensor on the board from the backside in the orientation shown in the image, and solder from the top surface. Make sure to align the ● mark on the silk with the ● mark on the board.   
  picot5400_bg_pmw3360_1

  With the sensor legs firmly in place, secure them with masking tape so that they do not float. Solder 16 legs from the top side. ***Soldering must be done wiht the USB cable disconnected.***  
  Remove the tape attached on the sensor and attached the lens from the top.    
  picot5400_bg_pmw3360_2

  picot5400_bg_pmw3360_3

  Once the lens is attached, connect it to the USB again and confirm that the cursor moves by moving your hand over the top of the lens.

  After confirming that the sensor is working correctly, apply a soldering iron slightly to the protrusion of the lens from the back side to melt and fix the lens.
  picot5400_bg_pmw3360_4  

### Ball Case

　Cut three pieces of the thinner silicone tubes about 3mm long. They can be easily cut with scissors, but be careful to keep the cut surfaces as flat as possible.  
  picot5400_bg_ballcase_1  

  Pass stainless pins through cut-out silicone tubes.  
  picot5400_bg_ballcase_2  

  Pass the bearing rollers through the outside of the silicone tubes and adjust them so that they are centered on the pins.  
  picot5400_bg_ballcase_3  

  Attach the pins with bearing rollers to the three pedestals of the ball case base. Push them in from directly above until you hear them click into place. If the pins do not stick out from the base, it should be ok.
  picot5400_bg_ballcase_4  

  Fix the spacers in the four corner below ball case base.  
  picot5400_bg_ballcase_5  

  Put ball case base above picot5400. Put them above a case or a bottom plate depending on keyboards, fix them with screws from the bottom side. Please refer to the build guide of each keyboard for more information.  
  picot5400_bg_ballcase_6  

## Firmware

  If you wish to write your own firmware, please follow the instructions below.

  - Press the RESET button while holding down the BOOT button on the picot5400 to enter boot loader mode.
  - The firmware is written by dragging and dropping the [.uf2](https://github.com/aki27kbd/picot5400/blob/main/firmware/aki27_picot5400_vial.uf2)file into the drive named RPI-RP2.  　

  Keymap is editable from [vial](https://vial.rocks/).  
  You can confirm that keys and trackball are working correctly with this firmware.

  The default firmware enables "Auto Mouse Layer", with which you can automatically jump into a specific mouse layer when you move trackball. You can toggle on/off this function with the custom keycode `AM_TOG`.

  The source code is available [here](https://github.com/aki27kbd/vial-qmk/tree/vial/keyboards/aki27/picot5400).

## Custom Keycodes

  Several custom key codes can be set for trackball operation.

  Keycode   |Description
  ---------|-----------
  `CPI_SW`  |Change the CPI of the trackball. With the default firmware, each press changes the CPI in the following order: 200 -> 400 -> 800 -> 1600 -> 3200 -> 200....
  `SCRL_SW` |Changes the sensitivity of the sensor in scroll mode. The higher the value, the smaller the amount of scrolling.
  `ROT_R15` |Turns the Y axis of the mouse sensor 15 degrees clockwise.
  `ROT_L15` |Rotate the Y axis of the mouse sensor 15 degrees counterclockwise.
  `SCRL_MO` |	Enables scroll mode for as long as it is pressed.
  `SCRL_TO` |Toggles between scroll mode and mouse mode each time it is pressed.
  `SCRL_IN` |Inverts the scroll direction.
  `AM_TOG` |Toggle the function of auto mouse layer.

  Custom key codes can be set in vial using the custom key code under the User tab.  
  CustomKeycode_rev

## Notes
If you have any problems, please contact us at[Twitter](https://twitter.com/aki27kbd).

The hashtag is #picot5400.

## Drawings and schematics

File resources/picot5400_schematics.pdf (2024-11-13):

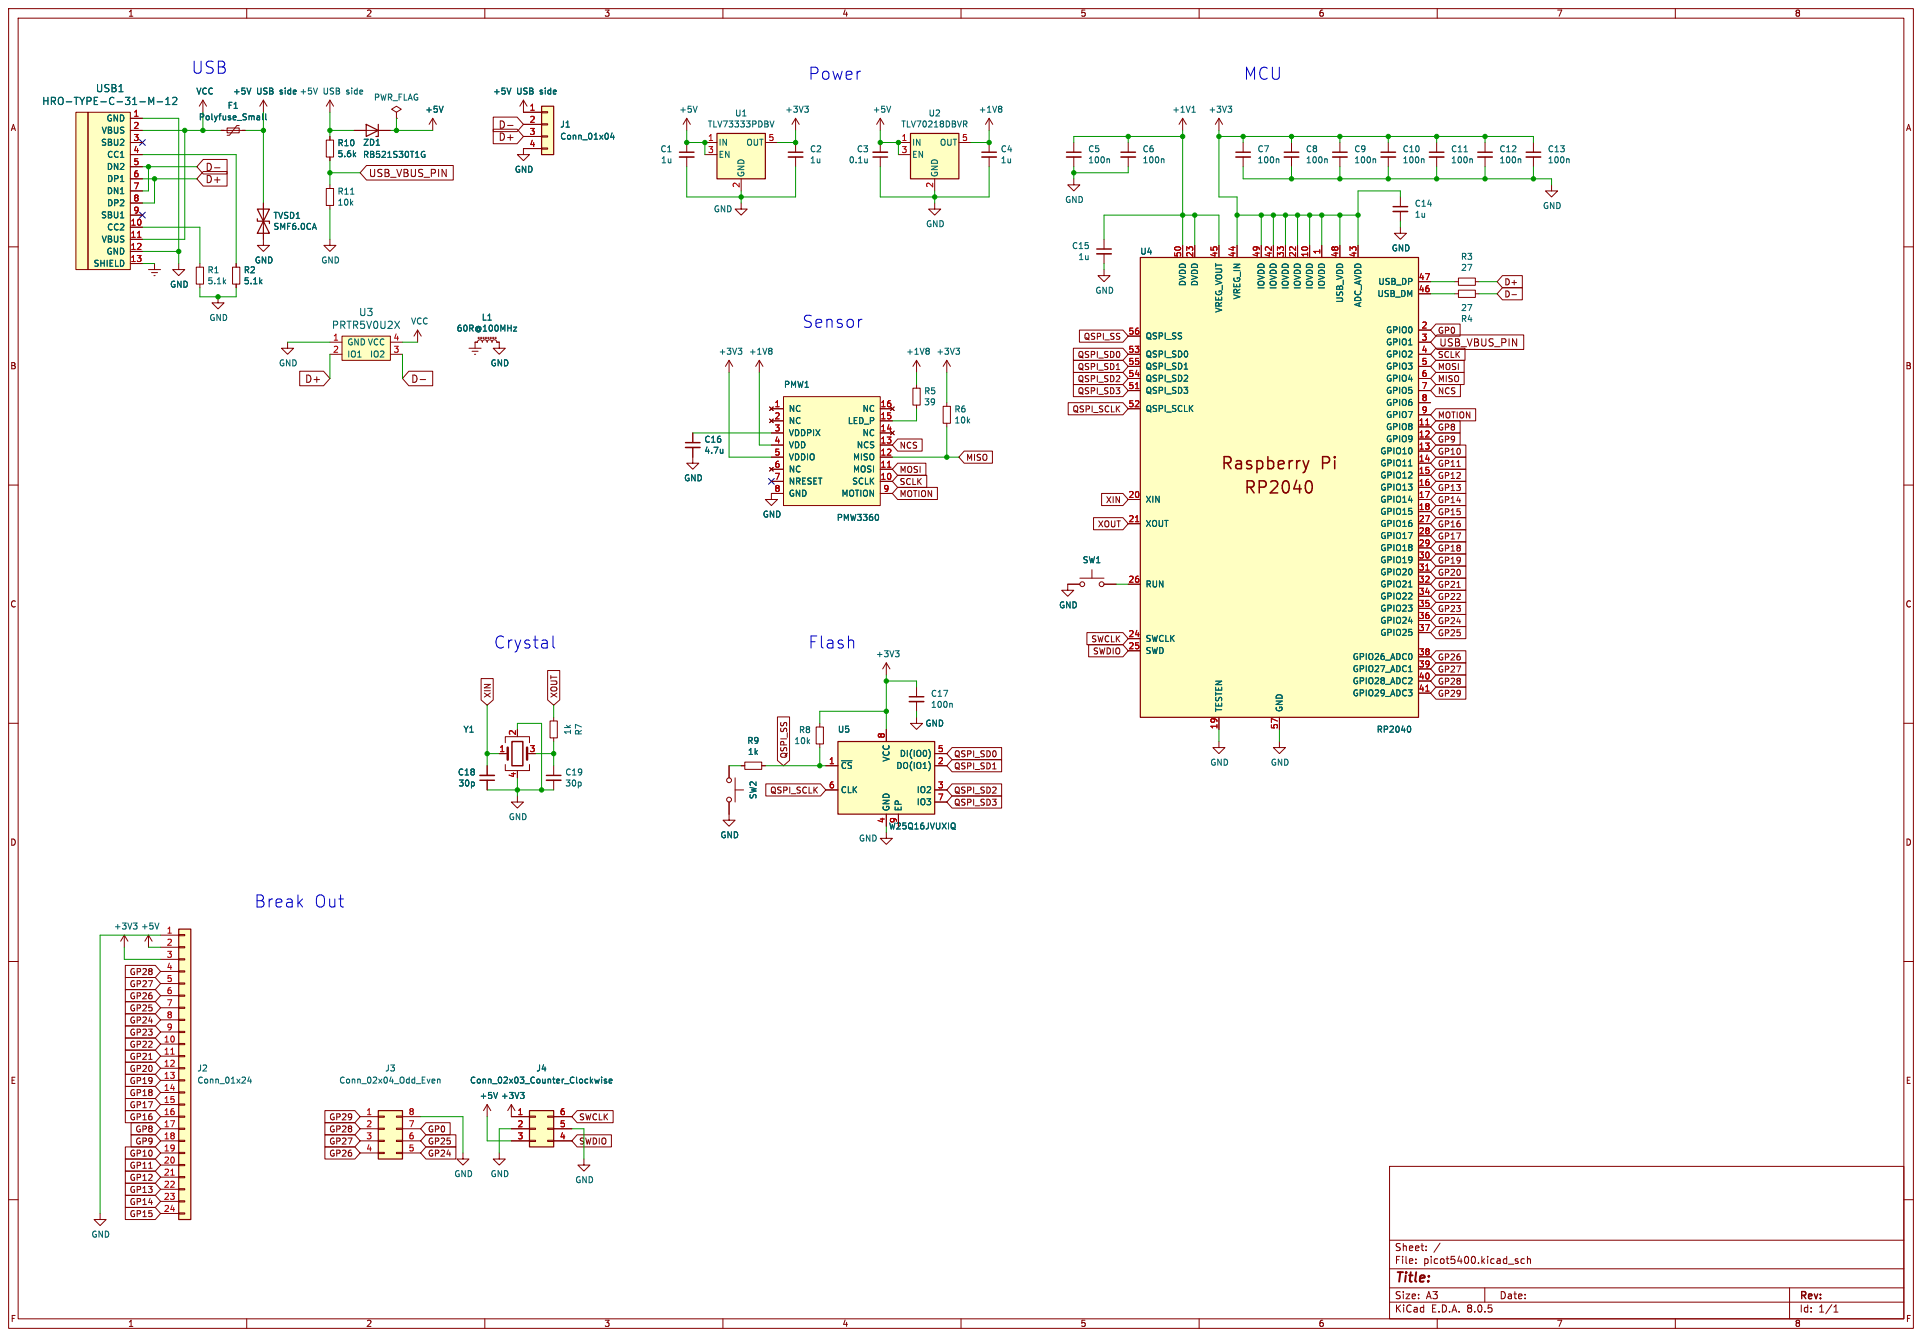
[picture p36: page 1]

5.1k VCC GND 1 CC2 10 VBUS 11 GND 12 SHIELD 13 VBUS 2 SBU2 3 CC1 4 DN2 5 DP1 6 DN1 7 DP2 8 SBU1 9 USB1

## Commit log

2024-11-13 add documents
    [picot5400_case_sample.step, picot5400_case_sample_8deg.step]
2024-11-13 revise case of O44 to o44 in images
2024-11-14 add ffc connector
